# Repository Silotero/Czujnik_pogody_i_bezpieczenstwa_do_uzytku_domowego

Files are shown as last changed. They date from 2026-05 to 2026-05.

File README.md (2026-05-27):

# Czujnik_pogody_i_bezpieczenstwa_do_uzytku_domowego
This is a device packed with MQ-7 (CO gas sensor), MQ-2 (smoke sensor), IR fire detector, as well as AHT20 (temperature and humidity sensor), along with the BMP280 (pressure sensor).

It is battery powered with USB-C non PD charging, usiong the MCP73831 battery charge IC, capable of charging the battery with 500 mA, with an AP9101 battery protection IC. The microcontroller used in this project is a barebone ESP32-C3, with external 4 MB of FLASH memory, using QSPI. The power coming from the battery gets passed to the PAM2423 boost converter circuit that boosts the battery voltage up to 5V. The 2 devices that use 5V (MQ-7 and MQ-2) are powered directly out of that output, while the rest such as the ESP32-C3, its FLASH memory, along with the AHT20 and BMP280 gets their 3.3V voltage out of a AP2114HA LDO

The ESP32-C3 RF pin is connected to an external antenna connector (IPEX4), used for transmitting data wirelessly.

The project is meant for use with a MQTT setup for data collection on a server type device.

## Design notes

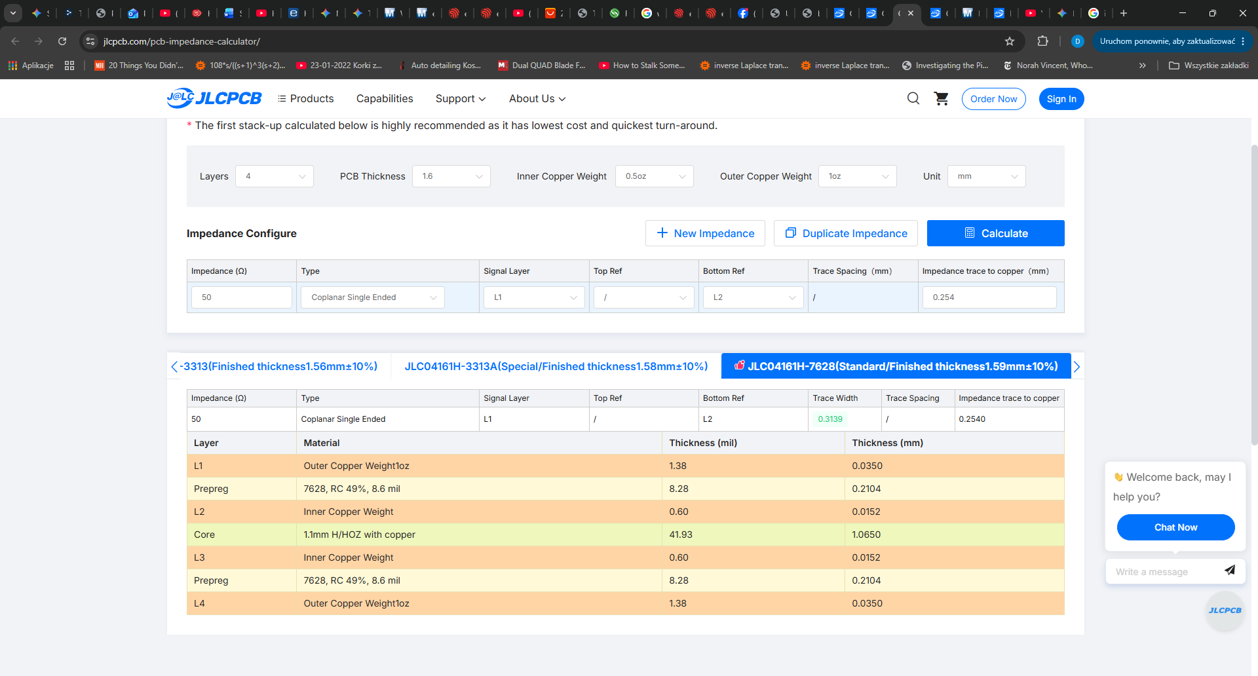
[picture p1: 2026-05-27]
Notes/Ścieżka dla anteny.png

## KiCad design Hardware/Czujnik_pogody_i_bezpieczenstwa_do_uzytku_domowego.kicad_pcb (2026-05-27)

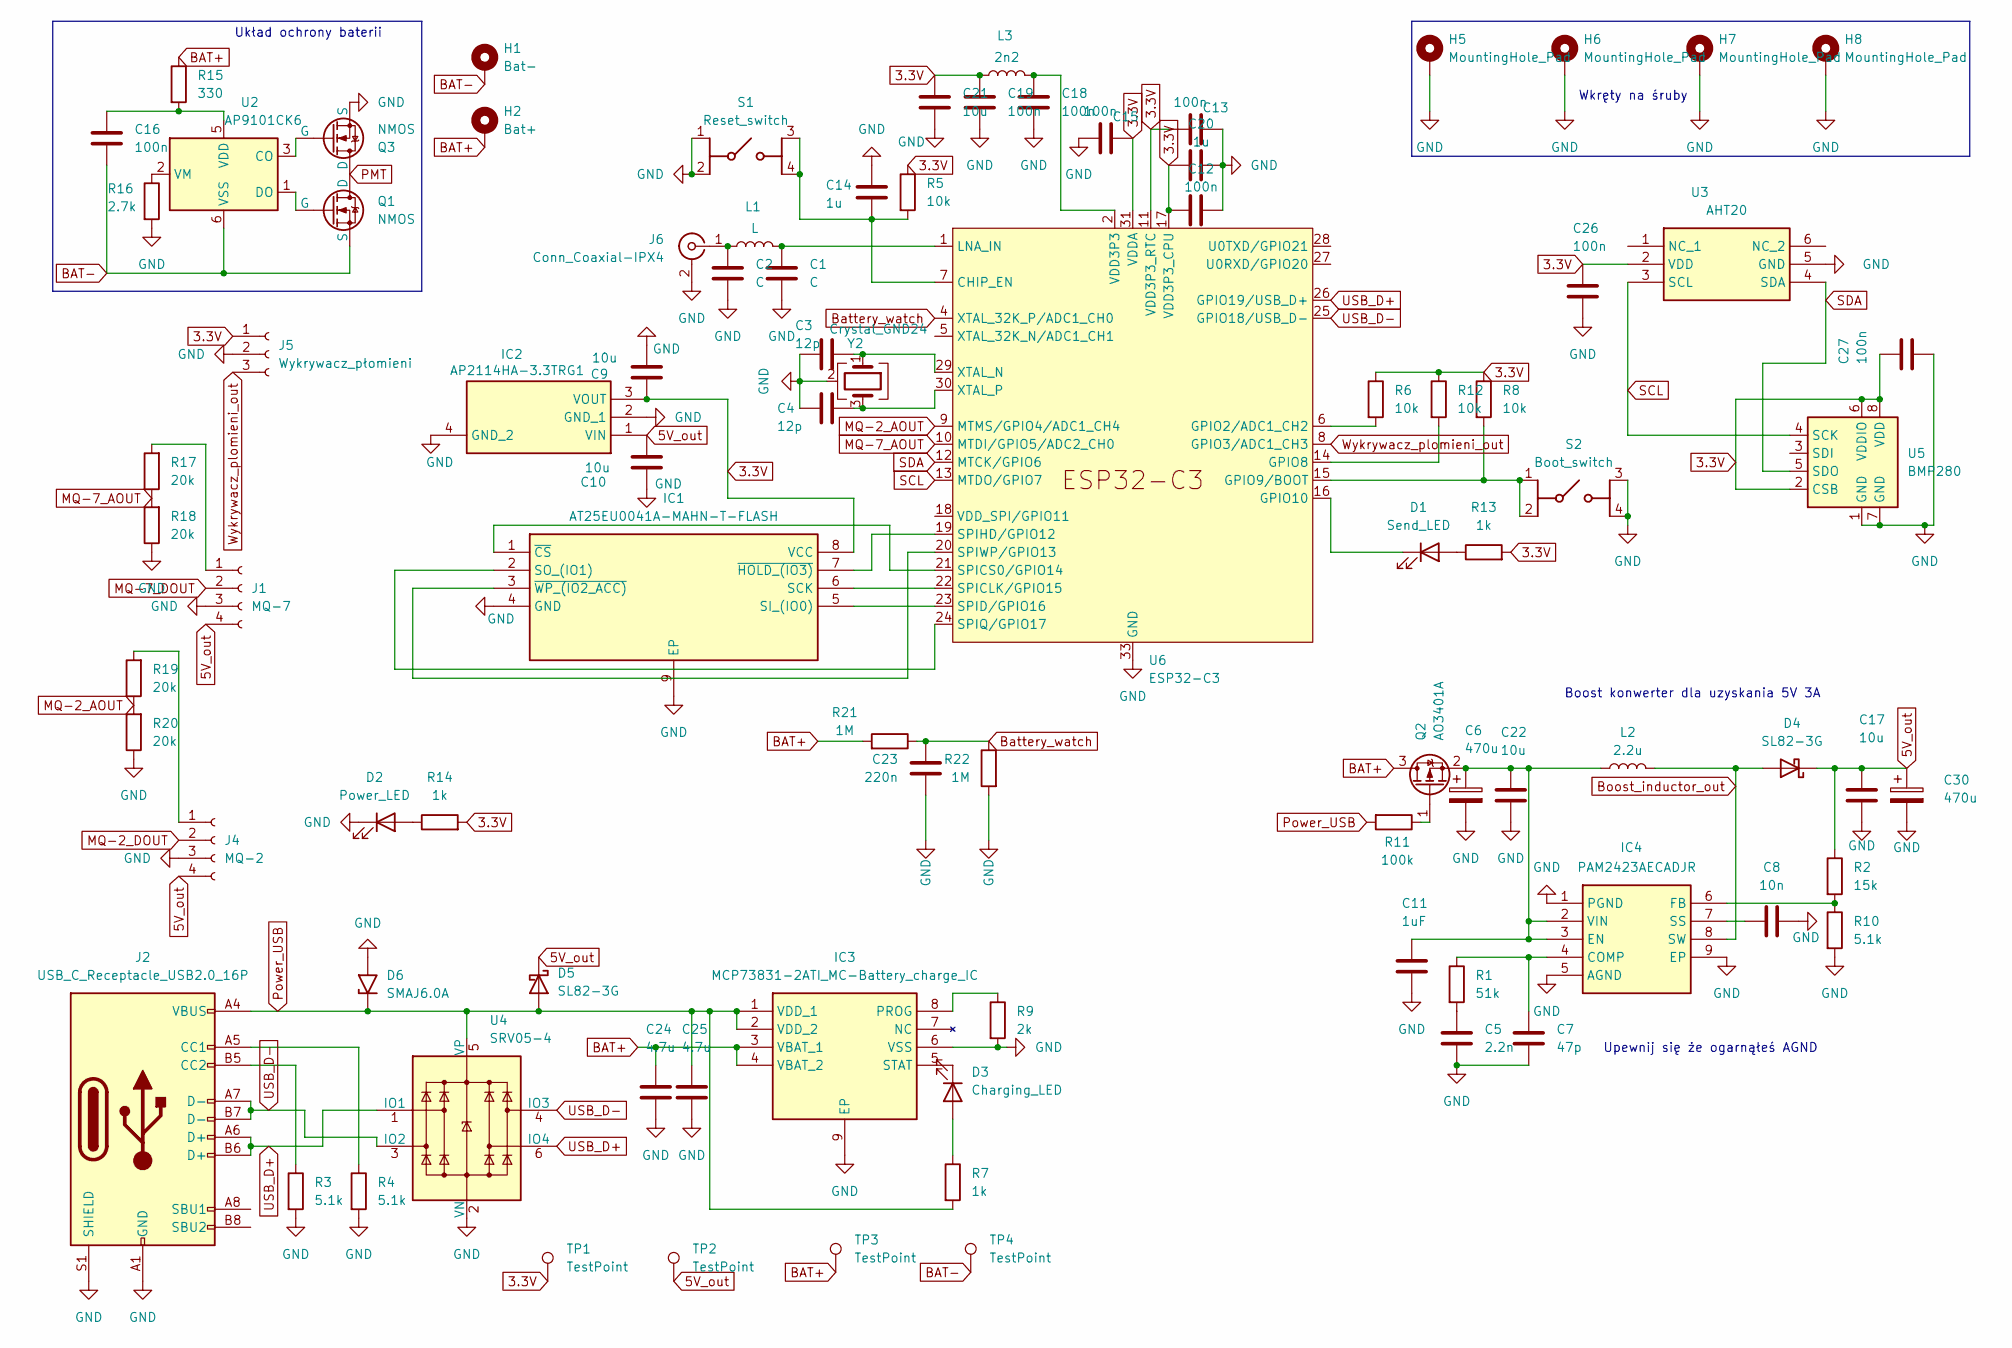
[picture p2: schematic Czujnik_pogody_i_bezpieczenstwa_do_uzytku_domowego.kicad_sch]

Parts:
C1, C2: C; C_0603_1608Metric
C3, C4: 12p; C_0603_1608Metric
C5: 2.2n; C_0603_1608Metric
C6, C30: 470u; CP_Radial_D10.0mm_P5.00mm
C7: 47p; C_0603_1608Metric
C8: 10n; C_0603_1608Metric
C9, C10, C17, C21, C22: 10u; C_0603_1608Metric
C11: 1uF; C_0603_1608Metric
C12, C13, C15, C16, C18, C19, C26, C27: 100n; C_0603_1608Metric
C14, C20: 1u; C_0603_1608Metric
C23: 220n; C_0603_1608Metric
C24, C25: 4.7u; C_0603_1608Metric
D1: Send_LED; LED_0603_1608Metric
D2: Power_LED; LED_0603_1608Metric
D3: Charging_LED; LED_0603_1608Metric
D4, D5: SL82-3G; D_SMC
D6: SMAJ6.0A; D_SMA
H1: Bat-; MountingHole_2.2mm_M2_DIN965_Pad_TopBottom
H2: Bat+; MountingHole_2.2mm_M2_DIN965_Pad_TopBottom
H5, H6, H7, H8: MountingHole_Pad; MountingHole_2.2mm_M2_DIN965_Pad
IC1: AT25EU0041A-MAHN-T-FLASH; SON50P300X200X60-9N-D; Manufacturer_Part_Number AT25EU0041A-MAHN-T; Mouser Part Number 968-AT25EU0041AMAHNT
IC2: AP2114HA-3.3TRG1; SOT230P700X180-4N; Manufacturer_Part_Number AP2114HA-3.3TRG1; Mouser Part Number 621-AP2114HA-3.3TRG1
IC3: MCP73831-2ATI_MC-Battery_charge_IC; SON50P300X200X100-9N-D; Manufacturer_Part_Number MCP73831-2ATI/MC; Mouser Part Number 579-MCP73831-2ATI/MC
IC4: PAM2423AECADJR; PAM2421AECADJR; Manufacturer_Part_Number PAM2421AECADJR; Mouser Part Number 621-PAM2421AECADJR
J1: MQ-7; PinSocket_1x04_P2.54mm_Vertical
J2: USB_C_Receptacle_USB2.0_16P; USB_C_Receptacle_GCT_USB4105-xx-A_16P_TopMnt_Horizontal
J4: MQ-2; PinSocket_1x04_P2.54mm_Vertical
J5: Wykrywacz_płomieni; PinSocket_1x03_P2.54mm_Vertical
J6: Conn_Coaxial-IPX4; IPX4
L1: L; L_0603_1608Metric
L2: 2.2u; DR127
L3: 2n2; L_0603_1608Metric
Q1, Q3: NMOS; SOP-8_3.76x4.96mm_P1.27mm
Q2: AO3401A; SOT-23
R1: 51k; R_0805_2012Metric
R2: 15k; R_0805_2012Metric
R3, R4, R10: 5.1k; R_0805_2012Metric
R5, R6, R8, R12: 10k; R_0805_2012Metric
R7, R13, R14: 1k; R_0805_2012Metric
R9: 2k; R_0805_2012Metric
R11: 100k; R_0805_2012Metric
R15: 330; R_0805_2012Metric
R16: 2.7k; R_0805_2012Metric
R17, R18, R19, R20: 20k; R_0805_2012Metric
R21, R22: 1M; R_0805_2012Metric
S1: Reset_switch; RKC2SJM170SMTRLFS; Manufacturer_Part_Number RKC2SJM170SMTRLFS; Mouser Part Number 611-KC2SJM170SMTRLFS
S2: Boot_switch; RKC2SJM170SMTRLFS; Manufacturer_Part_Number RKC2SJM170SMTRLFS; Mouser Part Number 611-KC2SJM170SMTRLFS
TP1, TP2, TP3, TP4: TestPoint; TestPoint_THTPad_D1.0mm_Drill0.5mm
U2: AP9101CK6; SOT-23-6
U3: AHT20; Manufacturer_Part_Number AHT20
U4: SRV05-4; SOT-23-6
U5: BMP280; Bosch_LGA-8_2x2.5mm_P0.65mm_ClockwisePinNumbering
U6: ESP32-C3; QFN-32-1EP_5x5mm_P0.5mm_EP3.45x3.45mm
Y2: Crystal_GND24; Crystal_SMD_3225-4Pin_3.2x2.5mm

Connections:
3.3V: C9.1, C12.1, C13.1, C15.2, C19.1, C20.1, C21.1, C26.1, C27.1, IC1.8 (VCC), IC2.3 (VOUT), J5.1, L3.1, R5.1, R6.1, R8.1, R12.1, R13.2, R14.2, TP1.1, U3.2 (VDD), U5.2 (CSB), U5.6 (VDDIO), U5.8 (VDD), U6.11 (VDD3P3_RTC), U6.17 (VDD3P3_CPU), U6.31 (VDDA), U6.32 (VDDA); also elsewhere on the board
5V_out: C10.2, C17.1, C30.1, D4.1 (K), D5.1 (K), IC2.1 (VIN), J1.4, J4.4, R2.1, TP2.1; also elsewhere on the board
BAT+: C24.1, H2.1, IC3.3 (VBAT_1), IC3.4 (VBAT_2), Q2.3 (D), R15.1, R21.2, TP3.1; also elsewhere on the board
BAT-: C16.2, H1.1, Q1.3 (S), TP4.1, U2.6 (VSS); also elsewhere on the board
Battery_watch: C23.1, R21.1, R22.1, U6.4 (XTAL_32K_P/ADC1_CH0)
Boost_inductor_out: D4.2 (A), IC4.8 (SW), L2.2
GND: C1.2, C2.1, C3.2, C4.2, C5.2, C6.2, C7.2, C8.2, C9.2, C10.1, C11.2, C12.2, C13.2, C14.2, C15.1, C17.2, C18.2, C19.2, C20.2, C21.2, C22.2, C23.2, C24.2, C25.2, C26.2, C27.2, C30.2, D2.1 (K), D6.2 (A2), H5.1, H6.1, H7.1, H8.1, IC1.4 (GND), IC1.9 (EP), IC2.2 (GND_1), IC2.4 (GND_2), IC3.6 (VSS), IC3.9 (EP), IC4.1 (PGND), IC4.5 (AGND), IC4.9 (EP), J1.3, J2.A1 (GND), J2.A12 (GND), J2.B1 (GND), J2.B12 (GND), J2.S1 (SHIELD), J4.3, J5.2, J6.2 (Ext), Q3.3 (S), R3.2, R4.2, R9.2, R10.2, R16.2, R18.1, R20.1, R22.2, S1.1 (COM_1), S1.2 (COM_2), S2.3 (NO_1), S2.4 (NO_2), U3.5 (GND), U4.2 (VN), U5.1 (GND), U5.7 (GND), U6.33 (GND), Y2.2 (G), Y2.4 (G)
MQ-2_AOUT: R19.1, R20.2, U6.9 (MTMS/GPIO4/ADC1_CH4)
MQ-2_DOUT: J4.2
MQ-7_AOUT: R17.1, R18.2, U6.10 (MTDI/GPIO5/ADC2_CH0)
MQ-7_DOUT: J1.2
unnamed: C5.1, R1.2
unnamed: C18.1, L3.2, U6.2 (VDD3P3), U6.3 (VDD3P3)
unnamed: D1.2 (A), R13.1
unnamed: D1.1 (K), U6.16 (GPIO10)
unnamed: D2.2 (A), R14.1
unnamed: D3.2 (A), R7.1
unnamed: D3.1 (K), IC3.5 (STAT)
unnamed: IC1.6 (SCK), U6.22 (SPICLK/GPIO15)
unnamed: IC1.5 (SI_(IO0)), U6.23 (SPID/GPIO16)
unnamed: IC1.2 (SO_(IO1)), U6.24 (SPIQ/GPIO17)
unnamed: IC1.1 (~CS), U6.21 (SPICS0/GPIO14)
unnamed: IC1.7 (~HOLD_(IO3)), U6.19 (SPIHD/GPIO12)
unnamed: IC1.3 (~WP_(IO2_ACC)), U6.20 (SPIWP/GPIO13)
unnamed: IC3.8 (PROG), R9.1
unnamed: C7.1, IC4.4 (COMP), R1.1
unnamed: C6.1, C11.1, C22.1, IC4.2 (VIN), IC4.3 (EN), L2.1, Q2.2 (S)
unnamed: IC4.6 (FB), R2.2, R10.1
unnamed: C8.1, IC4.7 (SS)
unnamed: J1.1, R17.2
unnamed: J2.A5 (CC1), R4.1
unnamed: J2.B5 (CC2), R3.1
unnamed: J4.1, R19.2
unnamed: C2.2, J6.1 (In), L1.1
unnamed: Q1.2 (G), U2.1 (DO)
unnamed: Q2.1 (G), R11.1
unnamed: Q3.2 (G), U2.3 (CO)
unnamed: C14.1, R5.2, S1.3 (NO_1), S1.4 (NO_2), U6.7 (CHIP_EN)
unnamed: R8.2, S2.1 (COM_1), S2.2 (COM_2), U6.15 (GPIO9/BOOT)
unnamed: C16.1, R15.2, U2.5 (VDD)
unnamed: R16.1, U2.2 (VM)
unnamed: R6.2, U6.6 (GPIO2/ADC1_CH2)
unnamed: R12.2, U6.14 (GPIO8)
unnamed: C1.1, L1.2, U6.1 (LNA_IN)
unnamed: C3.1, U6.29 (XTAL_N), Y2.1
unnamed: C4.1, U6.30 (XTAL_P), Y2.3
PMT: Q1.1 (D), Q3.1 (D)
Power_USB: C25.1, D5.2 (A), D6.1 (A1), IC3.1 (VDD_1), IC3.2 (VDD_2), J2.A4 (VBUS), J2.A9 (VBUS), J2.B4 (VBUS), J2.B9 (VBUS), R7.2, R11.2, U4.5 (VP)
SCL: U3.3 (SCL), U5.4 (SCK), U6.13 (MTDO/GPIO7)
SDA: U3.4 (SDA), U5.5 (SDO), U6.12 (MTCK/GPIO6)
USB_D+: J2.A6 (D+), J2.B6 (D+), U4.1 (IO1), U4.6 (IO4), U6.26 (GPIO19/USB_D+)
USB_D-: J2.A7 (D-), J2.B7 (D-), U4.3 (IO2), U4.4 (IO3), U6.25 (GPIO18/USB_D-)
Wykrywacz_plomieni_out: J5.3, U6.8 (GPIO3/ADC1_CH3)

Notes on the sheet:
Układ ochrony baterii
Wkręty na śruby
Boost konwerter dla uzyskania 5V 3A
Upewnij się że ogarnąłeś AGND

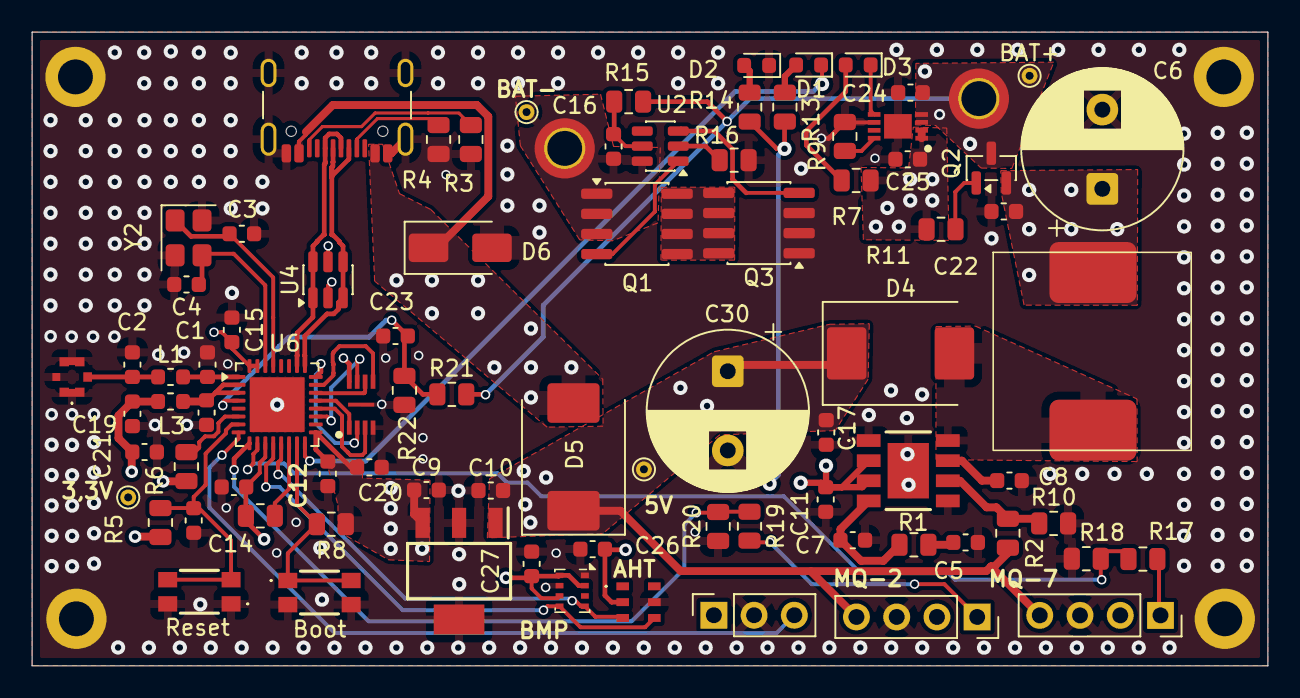
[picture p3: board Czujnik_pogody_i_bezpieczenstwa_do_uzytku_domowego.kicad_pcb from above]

Board: 4 copper layers, 78.0 x 40.0 mm, 89 parts (0 on the bottom side), 51 nets.

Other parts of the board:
3,3V, 5V: TestPoint; TestPoint_THTPad_D1.0mm_Drill0.5mm
BAT+: TestPoint; TestPoint_THTPad_D1.0mm_Drill0.5mm
BAT-: TestPoint; TestPoint_THTPad_D1.0mm_Drill0.5mm

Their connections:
3.3V: 3,3V.1; also elsewhere on the board
5V_out: 5V.1; also elsewhere on the board
BAT+: BAT+.1; also elsewhere on the board
BAT-: BAT-.1; also elsewhere on the board

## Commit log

2026-05-22 Added git ignore, created kicad start files
    [Czujnik_pogody_i_bezpieczenstwa_do_uzytku_domowego.kicad_pcb, Czujnik_pogody_i_bezpieczenstwa_do_uzytku_domowego.kicad_sch]
2026-05-25 Update po dużej ilości pracy
    Schemat raczej już skończony.
    [Czujnik_pogody_i_bezpieczenstwa_do_uzytku_domowego.kicad_pcb, Czujnik_pogody_i_bezpieczenstwa_do_uzytku_domowego.kicad_sch]
2026-05-27 Projekt ukończony
    [Czujnik_pogody_i_bezpieczenstwa_do_uzytku_domowego.kicad_pcb, Czujnik_pogody_i_bezpieczenstwa_do_uzytku_domowego.kicad_sch]
